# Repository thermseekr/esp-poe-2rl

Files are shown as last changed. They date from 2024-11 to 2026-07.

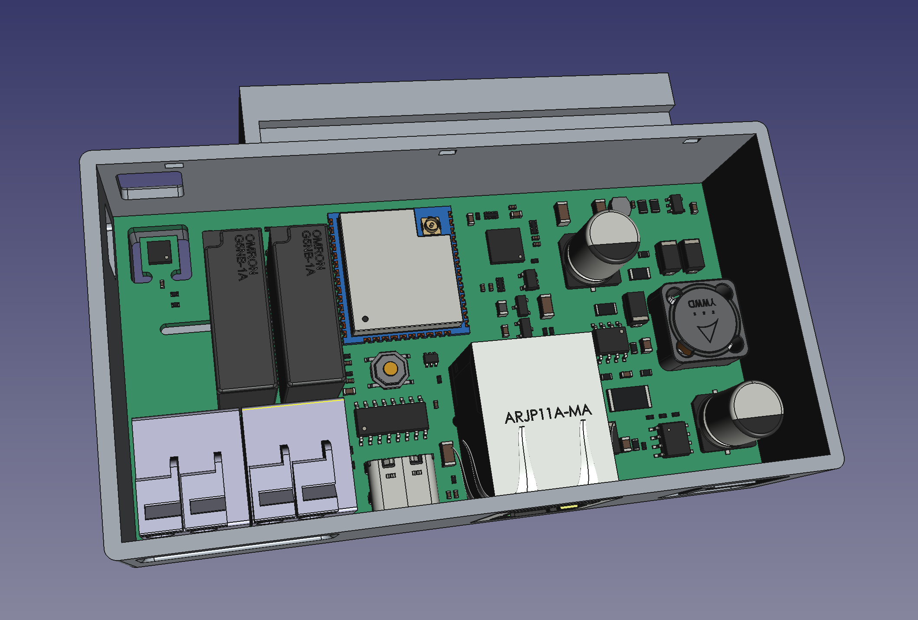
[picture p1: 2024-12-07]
V1/case-inside.png

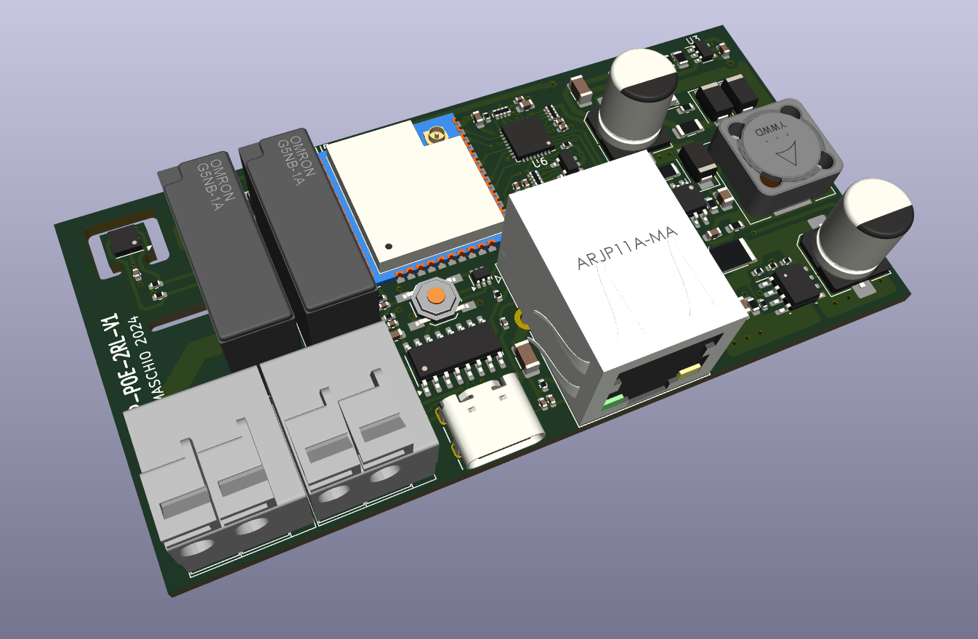
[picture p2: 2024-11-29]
V1/esp-poe-2rl-V1.1.0.png

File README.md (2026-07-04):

# eumesmo-poe-2rl
PoE powered ESP32 based board featuring two SPST NO relays. Ideal for access control, doors, isolated zones or for installing anywhere you need to click dry contacts near some equipment or appliance.

eumesmo-poe-2rl

## VERSION HISTORY

V1.6 - 2026/07/02 - Added CPU health LED.

V1.5 - 2026/06/13 - Repository renamed from ESP-POE-2RL to eumesmo-poe-2rl to align the design with the **eumesmo** line of building automation products.

V1.4 - 2026/06/10 - Terminal blocks replaced for 3.5mm pitch. Deleted temperature sensor, board decreased 8mm in length. LAN8710A rotated for shorter traces. Pull-up resistor for MDIO adjusted from 2.2k to 1.5k as suggested in the datasheet. Bulk and decoupling capacitor sizes and types adjusted for better performance.

V1.3 - 2025/06/29 - Layers reordered and board fully rerouted for better signal integrity.

V1.2 - 2024/12/07 - Connectors adjusted for best fitting the case.

V1.1 - 2024/11/29 - Initial release.

## LICENSE

This project is licensed under the [Creative Commons BY-NC 4.0 License](https://creativecommons.org/licenses/by-nc/4.0/).
Commercial use is not permitted without prior written consent. See the [LICENSE.txt](LICENSE.txt) file for details.

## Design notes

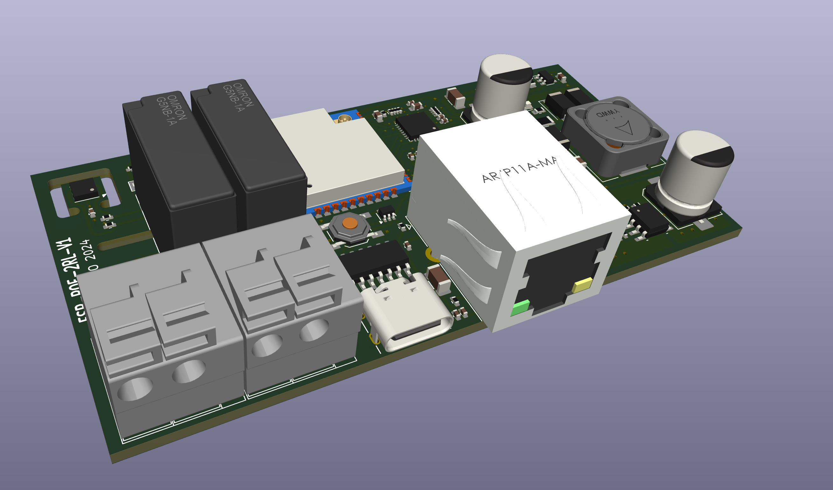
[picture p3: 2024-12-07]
V1/esp-poe-2rl-V1.2.0.png

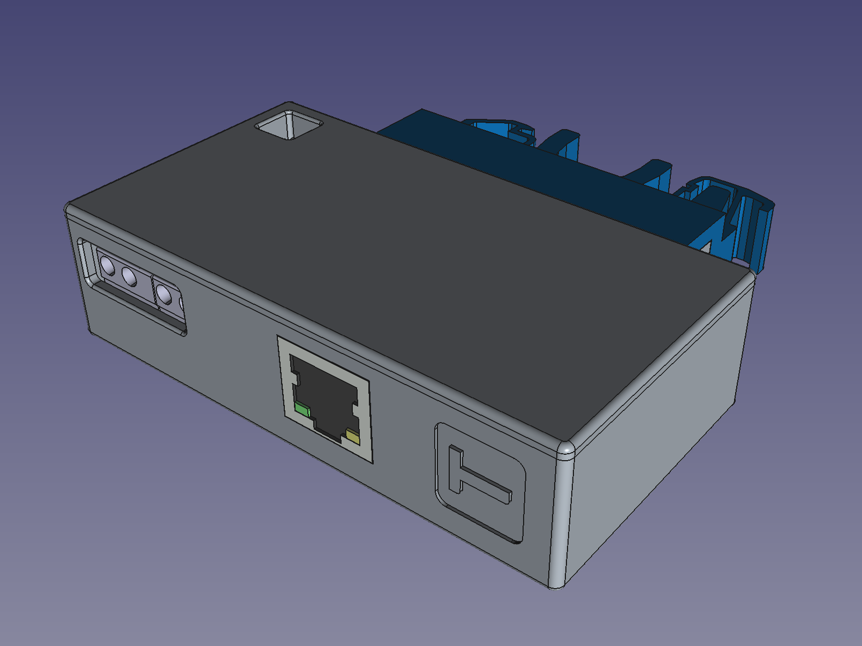
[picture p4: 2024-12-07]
V1/case-front.png

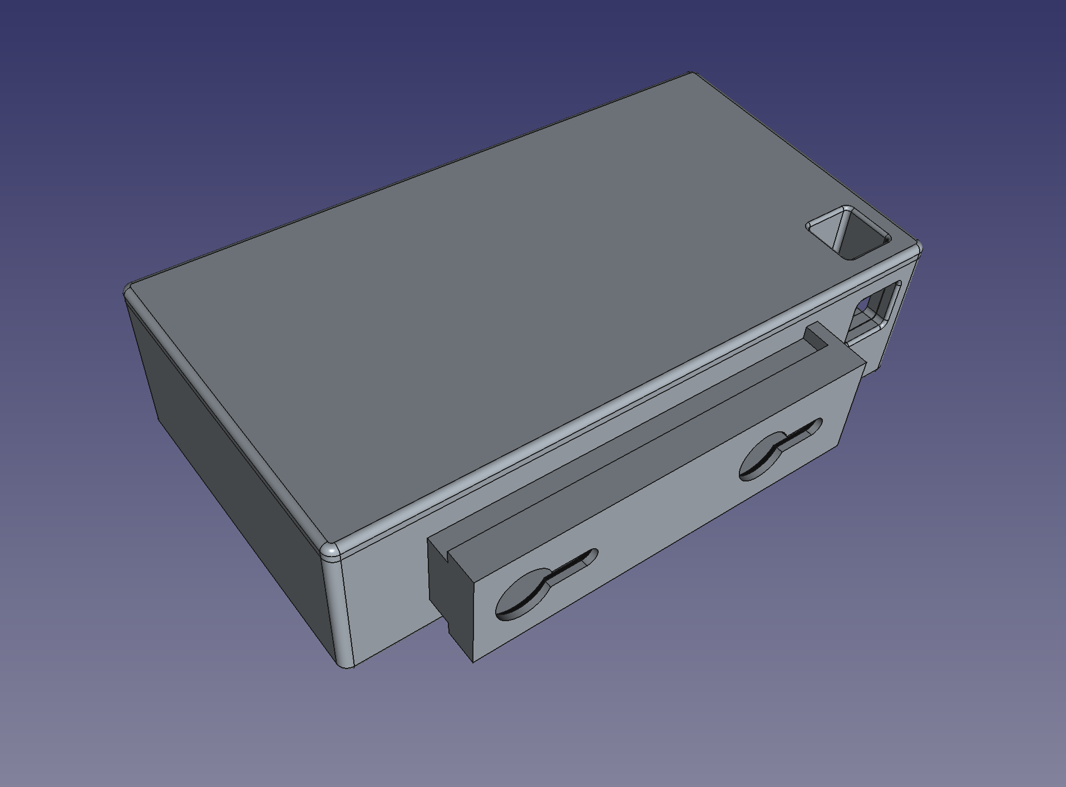
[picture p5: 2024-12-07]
V1/case-back-no-din.png

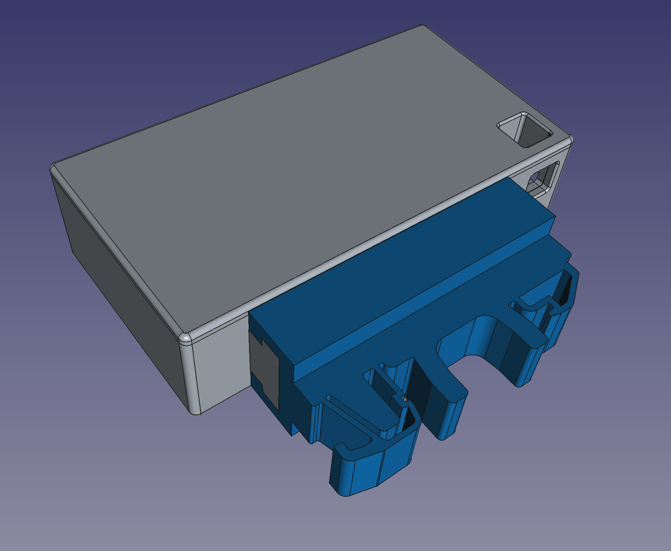
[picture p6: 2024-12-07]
V1/case-back.png

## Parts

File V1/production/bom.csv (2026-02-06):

Designator | Footprint | Quantity | Value | LCSC Part #
C1, C22, C25 | 1206 | 3 | 22uF/10V | C5672
C10, C11, C12, C13, C4, C6 | 0402 | 6 | 100nF/50V | C307331
C14, C18, C3, C5, C8 | 0603 | 5 | 10uF/10V | C19702
C15, C2, C7 | 0402 | 3 | 1uF/25V | C52923
C16 | 0402 | 1 | 470pF/50V | C1537
C17, C19 | 0805 | 2 | 100nF/100V | C28233
C20 | 0402 | 1 | 22pF/50V | C1555
C21 | 0603 | 1 | 12pF/50V | C38523
C23 | CP_Elec_8x10.5 | 1 | 22uF/100V | C178570
C24 | CP_Elec_8x10.5 | 1 | 470uF/16V | C96179
C9 | 1206 | 1 | 1nF/2kV | C161353
D1 | SOT-23-6 | 1 | USBLC6-2SC6 | C7519
D10, D2, D3 | 0603 | 3 | WHITE | C2290
D11 | D_SMA | 1 | SS510 | C65010
D4, D5 | D_SOD-123 | 2 | 1N4148 | C81598
D6 | SOT-23-5 | 1 | ESDS314DBV | C1847859
D7 | D_SMA | 1 | SMAJ58A | C132936
D8, D9 | D_SMA | 2 | SS34 | C8678
J1 | USB_C_Receptacle_GCT_USB4105-xx-A_16P_TopMnt_Horizontal | 1 | USB_C_Receptacle_USB2.0 | C2765186
J2, J3 | TerminalBlock_Dibo_DB142R-5.08-2P_1x02_P5.08mm_Horizontal | 2 | 1x2P 5,08mm | C475144
J4 | RJ45_HanRun_HY931147C | 1 | RJ45 JACK | C91754
K1, K2 | Relay_SPST_Omron_G5NB-1A | 2 | G5NB-1A-E-DC5 | C48746
L1 | 0805 | 1 | 2A/600R | C139168
L2 | L_12x12mm_h6mm | 1 | 33uH/2,1A | C169386
L3 | L_3x3mm_h1.5mm | 1 | 2,2uH/1,5A | C370424
Q1 | SOT-23 | 1 | WPM2015-3/TR | C558305
Q2 | SOT-23 | 1 | LMUN2211LT1G | C150229
Q3 | SOT-363_SC-70-6 | 1 | UMH3N | C62892
Q4, Q5 | SOT-23 | 2 | MMBT2222A | C8512
R1, R11, R12, R14, R15, R28, R5, R6 | 0402 | 8 | 10k | C60490
R10, R9 | 0402 | 2 | 680R | C25130
R13 | 0402 | 1 | 22R | C25092
R16 | 0402 | 1 | 12,1k | C25852
R17, R18 | 0402 | 2 | 330R | C25104
R19 | 1206 | 1 | 30mR/250mW | C473665
R2, R4 | 0402 | 2 | 5,1k | C105872
R20, R3, R7, R8 | 0402 | 4 | 1k | C11702
R21 | 0402 | 1 | 180k | C138046
R22 | 0402 | 1 | 30,1k | C138009
R23 | 0603 | 1 | 4,42k/100mW | C482858
R24 | 0603 | 1 | 5,1R/100mW | C25197
R25 | 0805 | 1 | 100k/0,125W | C149504
R26 | 0805 | 1 | 22,1k/0,125W | C17552
R27 | 0402 | 1 | 130k | C93946
R29 | 0603 | 1 | 300k/100mW | C23024
R30 | 0603 | 1 | 52,3k/100mW | C185323
R31 | 2512 | 1 | 4,7k/1W | C878291
R32, R33, R34, R35 | 0402 | 4 | 49,9R | C25120
R36, R37, R38, R39, R40, R41, R42, R43 | 0402 | 8 | 2k2 | C25879
SW1 | SW_SPST_Xunpu_TS1088AR02016 | 1 | RESET | C720477
U1 | SSOP-10-1EP_3.9x4.9mm_P1mm_EP2.1x3.3mm | 1 | CH340K | C968586
U2 | ESP32-WROOM-32U | 1 | ESP32-WROOM-32UE-N16 | C701346
U3 | QFN-32-1EP_5x5mm_P0.5mm_EP3.3x3.3mm_ThermalVias | 1 | LAN8710A | C46185
U4 | SOIC-8-1EP_3.9x4.9mm_P1.27mm_EP2.41x3.81mm_ThermalVias | 1 | TX4138 | C329267
U5 | SOT-23-5_Shorter_Pins | 1 | SY8089A1AAC | C479074
U6 | SOIC-8-1EP_3.9x4.9mm_P1.27mm_EP2.95x4.9mm_Mask2.71x3.4mm_ThermalVias | 1 | TPS2376DDAR-H | C544899

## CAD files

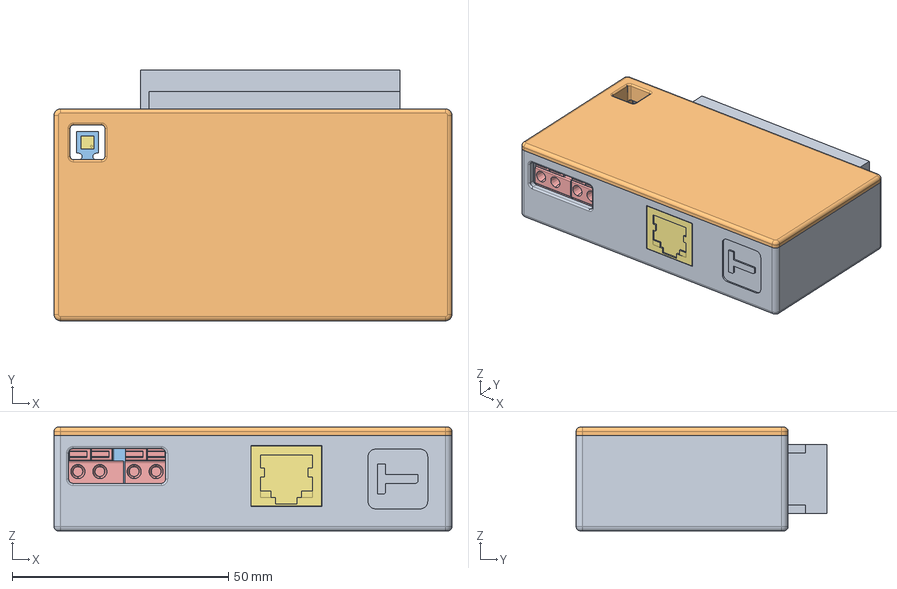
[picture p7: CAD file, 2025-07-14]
V1/esp-poe-2rl-V1.FCStd
92.0 x 58.0 x 24.0 mm
base
tampa
Pcb_c889
Q2_SOT_23_4970d7121a076 x 4
J3_DB142R-508-1P_a4dc8ad2a203 x 2
R23_R_0402_1005Metric_0b1d7b5ca681 x 24
C10_C_0402_1005Metric_ed852e6b843f001 x 12
SW1_3x4x2mm - 2 button_e5fc0649a69a
C6_C_0603_1608Metric_744dddbd0627 x 6
R8_R_0603_1608Metric_64182718e303 x 5
U6_QFN_32_1EP_5x5mm_P05mm_EP33x33mm_efa93686acdd001
D3_D_SMA_e0da9ef18898 x 4
C3_C_0805_2012Metric_58c3552bee014 x 2
U4_SOIC_16_39x99mm_P127mm_c005a263dd071
J2_ARJP11A_ARJP11A-MA_68af04fa2421
C8_C_1206_3216Metric_09ed0d5bb760 x 4
U5_ESP32-WROOM-32U_007640470fe010
U3_TSOT_23_5_e862bd6dc8b008
USB_C_Receptacle_16P_TopMnt_Horizontal_GCT_USB4105-xx-A036
USB_C_Receptacle_16P_TopMnt_Horizontal_GCT_USB4105-xx-A037
USB_C_Receptacle_16P_TopMnt_Horizontal_GCT_USB4105-xx-A038
USB_C_Receptacle_16P_TopMnt_Horizontal_GCT_USB4105-xx-A039
USB_C_Receptacle_16P_TopMnt_Horizontal_GCT_USB4105-xx-A040
USB_C_Receptacle_16P_TopMnt_Horizontal_GCT_USB4105-xx-A041
USB_C_Receptacle_16P_TopMnt_Horizontal_GCT_USB4105-xx-A042
USB_C_Receptacle_16P_TopMnt_Horizontal_GCT_USB4105-xx-A043
USB_C_Receptacle_16P_TopMnt_Horizontal_GCT_USB4105-xx-A044
USB_C_Receptacle_16P_TopMnt_Horizontal_GCT_USB4105-xx-A045
USB_C_Receptacle_16P_TopMnt_Horizontal_GCT_USB4105-xx-A046
USB_C_Receptacle_16P_TopMnt_Horizontal_GCT_USB4105-xx-A047
USB_C_Receptacle_16P_TopMnt_Horizontal_GCT_USB4105-xx-A048
USB_C_Receptacle_16P_TopMnt_Horizontal_GCT_USB4105-xx-A049
USB_C_Receptacle_16P_TopMnt_Horizontal_GCT_USB4105-xx-A050
USB_C_Receptacle_16P_TopMnt_Horizontal_GCT_USB4105-xx-A051
USB_C_Receptacle_16P_TopMnt_Horizontal_GCT_USB4105-xx-A052
USB_C_Receptacle_16P_TopMnt_Horizontal_GCT_USB4105-xx-A053
USB_C_Receptacle_16P_TopMnt_Horizontal_GCT_USB4105-xx-A054
USB_C_Receptacle_16P_TopMnt_Horizontal_GCT_USB4105-xx-A055
USB_C_Receptacle_16P_TopMnt_Horizontal_GCT_USB4105-xx-A056
USB_C_Receptacle_16P_TopMnt_Horizontal_GCT_USB4105-xx-A057
USB_C_Receptacle_16P_TopMnt_Horizontal_GCT_USB4105-xx-A058
USB_C_Receptacle_16P_TopMnt_Horizontal_GCT_USB4105-xx-A059
USB_C_Receptacle_16P_TopMnt_Horizontal_GCT_USB4105-xx-A060
USB_C_Receptacle_16P_TopMnt_Horizontal_GCT_USB4105-xx-A061
USB_C_Receptacle_16P_TopMnt_Horizontal_GCT_USB4105-xx-A062
USB_C_Receptacle_16P_TopMnt_Horizontal_GCT_USB4105-xx-A063
USB_C_Receptacle_16P_TopMnt_Horizontal_GCT_USB4105-xx-A064
USB_C_Receptacle_16P_TopMnt_Horizontal_GCT_USB4105-xx-A065
USB_C_Receptacle_16P_TopMnt_Horizontal_GCT_USB4105-xx-A066
USB_C_Receptacle_16P_TopMnt_Horizontal_GCT_USB4105-xx-A067
USB_C_Receptacle_16P_TopMnt_Horizontal_GCT_USB4105-xx-A068
USB_C_Receptacle_16P_TopMnt_Horizontal_GCT_USB4105-xx-A069
USB_C_Receptacle_16P_TopMnt_Horizontal_GCT_USB4105-xx-A070
USB_C_Receptacle_16P_TopMnt_Horizontal_GCT_USB4105-xx-A071
F1_Fuse_1206_3216Metric_39f227ff16b009
D5_LED_0603_1608Metric_6aec2e6d64af001 x 3
Q1_SOT_363_SC_70_6_453209e6e602
L3_L_0805_2012Metric_3eca19b2d063
C2_CP_Elec_8x105_1f412a5b28ca001 x 2
U7_DFN_6_1EP_3x3mm_Pitch1mm_b88c4946fe064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

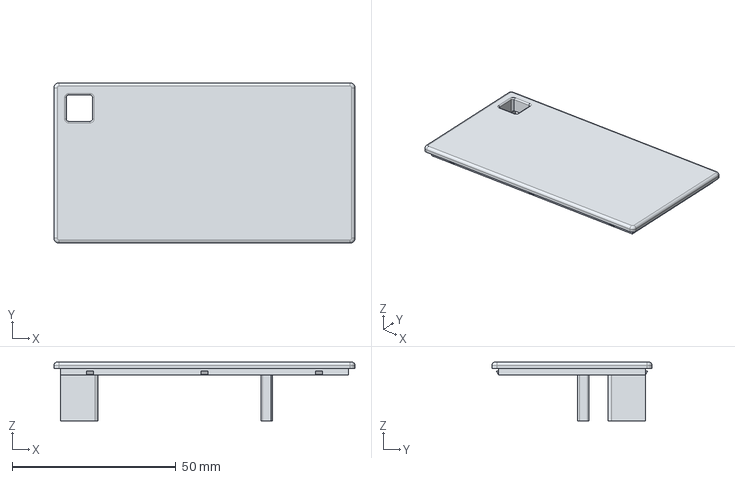
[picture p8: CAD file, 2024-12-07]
V1/esp-poe-2rl-V1-CaixaTampa.step
92.0 x 49.0 x 18.0 mm

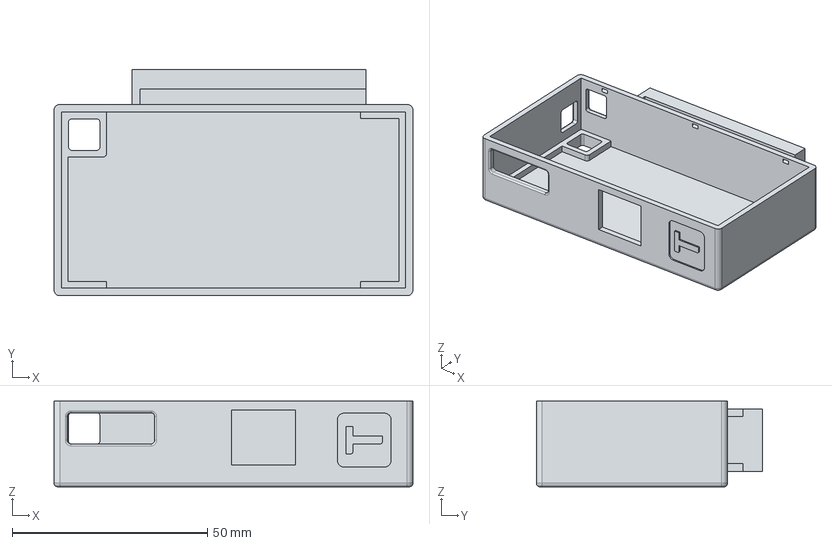
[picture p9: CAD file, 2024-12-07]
V1/esp-poe-2rl-V1-CaixaBase.step
92.0 x 58.0 x 22.0 mm

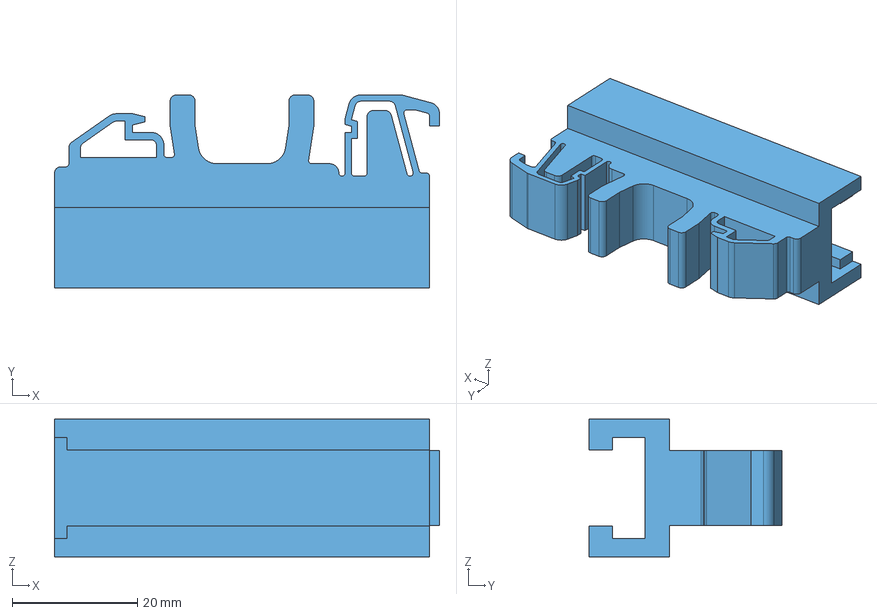
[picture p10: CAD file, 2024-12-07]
V1/esp-poe-2rl-V1-Encaixe-DIN.step
61.6 x 30.9 x 22.0 mm

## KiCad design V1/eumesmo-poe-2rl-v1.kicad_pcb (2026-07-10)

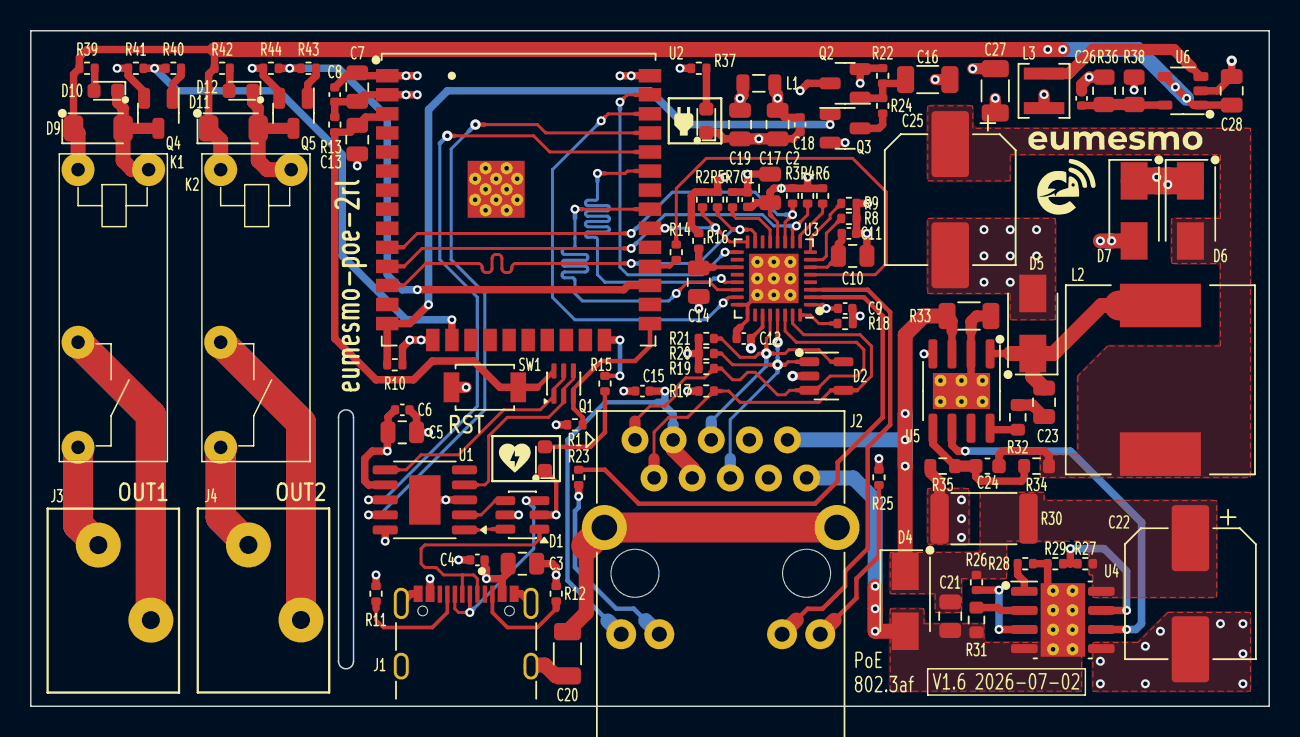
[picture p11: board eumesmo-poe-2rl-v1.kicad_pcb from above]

Board: 4 copper layers, 82.5 x 45.0 mm, 105 parts (0 on the bottom side), 77 nets.

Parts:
C1, C4, C6, C8, C9, C12, C15, C18: 100nF/50V; C_0402_1005Metric
C2, C5, C7, C14, C17, C19, C28: 10uF/25V; C_0805_2012Metric
C3, C10, C13: 1uF/50V; C_0805_2012Metric
C11: 470pF/50V; C_0402_1005Metric
C16, C27: 22uF/10V; C_1206_3216Metric
C20: 1nF/2kV; C_1206_3216Metric
C21, C23: 100nF/100V; C_0805_2012Metric
C22: 22uF/100V; CP_Elec_8x10.5
C24: 12pF/50V; C_0603_1608Metric
C25: 470uF/16V; CP_Elec_8x10.5
C26: 22pF/50V; C_0402_1005Metric
D1: USBLC6-2SC6; SOT-23-6
D2: ESDS314DBV; SOT-23-5
D3: WHITE/0603; LED_0603_1608Metric
D4: SMAJ58A; D_SMA
D5: SS510; D_SMA
D6, D7: SS34; D_SMA
D8, D10, D12: WHITE; LED_0603_1608Metric
D9, D11: 1N4148; D_SOD-123
J1: USB_C_Receptacle_USB2.0; USB_C_Receptacle_GCT_USB4105-xx-A_16P_TopMnt_Horizontal
J2: RJ45 JACK; RJ45_HanRun_HY931147C
J3, J4: 250-202; TerminalBlock_Wago_250-202_1x02_P3.5mm_45Degree
K1, K2: G5NB-1A-E-DC5; Relay_SPST_Omron_G5NB-1A
L1: 2A/600R; L_0805_2012Metric
L2: 33uH/2,1A; L_12x12mm_H6mm
L3: 2,2uH/1,5A; L_3x3mm_H1.5mm
Q1: UMH3N; SOT-363_SC-70-6
Q2: WPM2015-3/TR; SOT-23
Q3: LMUN2211LT1G; SOT-23
Q4, Q5: MMBT2222A; SOT-23
R1, R10, R13, R16, R22, R29, R41, R44: 10k; R_0402_1005Metric
R2: 1.5k; R_0402_1005Metric
R3, R4, R5, R6, R7, R8, R9: 2.2k; R_0402_1005Metric
R11, R12: 5,1k; R_0402_1005Metric
R14: 33R; R_0402_1005Metric
R15, R37: 300R; R_0402_1005Metric
R17, R19, R20, R21: 49,9R; R_0402_1005Metric
R18: 12,1k; R_0402_1005Metric
R23, R25: 330R; R_0402_1005Metric
R24, R40, R43: 1k; R_0402_1005Metric
R26: 30,1k; R_0402_1005Metric
R27: 130k; R_0402_1005Metric
R28: 180k; R_0402_1005Metric
R30: 4,7k/1W; R_2512_6332Metric
R31: 4,42k/100mW; R_0603_1608Metric
R32: 5,1R/100mW; R_0603_1608Metric
R33: 30mR/250mW; R_1206_3216Metric
R34: 300k/100mW; R_0603_1608Metric
R35: 52,3k/100mW; R_0603_1608Metric
R36: 100k/0,125W; R_0805_2012Metric
R38: 22,1k/0,125W; R_0805_2012Metric
R39, R42: 680R; R_0402_1005Metric
SW1: RESET; SW_SPST_Xunpu_TS1088AR02016
U1: CH340K; SSOP-10-1EP_3.9x4.9mm_P1mm_EP2.1x3.3mm
U2: ESP32-WROOM-32UE-N16; ESP32-WROOM-32U
U3: LAN8710A; QFN-32-1EP_5x5mm_P0.5mm_EP3.3x3.3mm_ThermalVias
U4: TPS2376DDAR-H; SOIC-8-1EP_3.9x4.9mm_P1.27mm_EP2.95x4.9mm_Mask2.71x3.4mm_Th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
U5: TX4138; SOIC-8-1EP_3.9x4.9mm_P1.27mm_EP2.41x3.81mm_ThermalVias
U6: SY8089A1AAC; SOT-23-5_Shorter_Pins

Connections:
5VPOE: C24.1, C25.1, D6.2 (A), L2.2, R34.1
5VUSB: C3.1, C4.1, D1.5 (VBUS), D7.2 (A), J1.A4 (VBUS), J1.A9 (VBUS), J1.B4 (VBUS), J1.B9 (VBUS)
+3V3: C5.1, C6.1, C7.1, C8.1, C16.1, C26.1, C27.1, L3.2, Q2.2 (S), R1.1, R13.1, R22.1, R36.1, R37.1, U1.7 (VCC), U1.10 (V3), U2.2 (VDD)
+3V3A: C9.1, C12.1, C15.1, C19.1, J2.3 (CT), J2.4 (CT), J2.11 (LLED+), L1.2, R17.2, R19.2, R20.2, R21.2, U3.1 (VDD2A), U3.27 (VDD1A)
+3V3LAN: C1.1, C2.1, C17.1, C18.1, L1.1, Q2.3 (D), R2.1, R3.1, R4.1, R5.1, R6.1, R16.2, U3.12 (VDDIO)
+5V: C28.1, D6.1 (K), D7.1 (K), D9.1 (K), D11.1 (K), K1.1, K2.1, R39.1, R42.1, U6.1 (EN), U6.4 (IN)
/CPULED: D3.2 (A), R15.2
/CPUOK: R15.1, U2.24 (IO2)
/EMACCLK: R14.2, U3.5 (XTAL1/CLKIN)
/EMACMDC: U2.37 (IO23), U3.17 (MDC)
/EMACMDIO: R2.2, U2.30 (IO18), U3.16 (MDIO)
/EMACRX: R5.2, U2.12 (IO27), U3.15 (COL/CRS_DV/~MODE2)
/EMACRXCLK: R8.2, U3.7 (RXCLK/~PHYAD1)
/EMACRXD0: R3.2, U2.10 (IO25), U3.11 (RXD0/~MODE0)
/EMACRXD1: R4.2, U2.11 (IO26), U3.10 (RXD1/~MODE1)
/EMACRXD2: R6.2, U3.9 (RXD2/~RMIISEL)
/EMACRXD3: R9.2, U3.8 (RXD3/~PHYAD2)
/EMACRXD4: R7.2, U3.13 (RXER/RXD4/~PHYAD0)
/EMACTXD0: U2.31 (IO19), U3.22 (TXD0)
/EMACTXD1: U2.36 (IO22), U3.23 (TXD1)
/EMACTXEN: U2.33 (IO21), U3.21 (TXEN)
/ESPCLK: R14.1, U2.28 (IO17)
/ESPEN: C13.1, Q1.6 (C1), R13.2, SW1.2, U2.3 (EN)
/ESPPROG: Q1.3 (C2), R1.2, U2.25 (IO0)
/ETHLEDGA: J2.13 (RLED+), U3.3 (LED1/~REGOFF)
/ETHLEDGK: J2.14 (RLED-), R25.2
/ETHLEDY: R23.2, U3.2 (LED2/~INTSEL)
/ETHLEDYK: J2.12 (LLED-), R23.1
/ETHRXD+: D2.4 (I/03), J2.2 (RD+), R17.1, U3.31 (RXP)
/ETHRXD-: D2.3 (I/02), J2.1 (RD-), R19.1, U3.30 (RXN)
/ETHSH: C20.1, J2.15 (SHIELD)
/ETHTXD+: D2.1 (I/01), J2.6 (TD+), R20.1, U3.29 (TXP)
/ETHTXD-: D2.5 (I/04), J2.5 (TD-), R21.1, U3.28 (TXN)
/PHYNRST: C14.2, R16.1, U3.19 (~RST)
/PHYPWRBJT: Q3.3 (C), R24.2
/PHYPWRFET: C16.2, Q2.1 (G), R22.2, R24.1
/POWER/3V3LED: D8.2 (A), R37.2
/POWER/3V3REF: C26.2, R36.2, R38.1, U6.5 (FB)
/POWER/3V3SW: L3.1, U6.3 (LX)
/POWER/5VBS: C23.1, R32.1
/POWER/5VREF: C24.2, R34.2, R35.1, U5.5 (FB)
/POWER/5VSW: C23.2, D5.1 (K), L2.1, U5.1 (SW)
/POWER/BS: R32.2, U5.8 (BS)
/POWER/ILIM: R33.2, U5.2 (ILIM), U5.9 (ILIM)
/POWER/RCLASS: R31.1, U4.2 (CLASS)
/POWER/RDET: R26.2, U4.3 (DET)
/POWER/RILIM: R28.1, U4.1 (ILIM)
/POWER/VTAP: R27.2, R29.1, U4.7 (UVLO)
/RBIAS: R18.1, U3.32 (RBIAS)
/RELAY OUTPUTS/OUT1BJT: Q4.1 (B), R40.1
/RELAY OUTPUTS/OUT1CMD: D9.2 (A), D10.1 (K), K1.4, Q4.3 (C)
/RELAY OUTPUTS/OUT1LD: J3.1, K1.3
/RELAY OUTPUTS/OUT1LN: J3.2, K1.2
/RELAY OUTPUTS/OUT1ON: D10.2 (A), R39.2
/RELAY OUTPUTS/OUT2BJT: Q5.1 (B), R43.1
/RELAY OUTPUTS/OUT2CMD: D11.2 (A), D12.1 (K), K2.4, Q5.3 (C)
/RELAY OUTPUTS/OUT2LD: J4.1, K2.3
/RELAY OUTPUTS/OUT2LN: J4.2, K2.2
/RELAY OUTPUTS/OUT2ON: D12.2 (A), R42.2
/UARTNDTR: Q1.2 (B1), Q1.4 (E2), U1.4 (~DTR)
/UARTNRTS: Q1.1 (E1), Q1.5 (B2), U1.6 (~RTS)
/UARTRXD: U1.9 (RXD), U2.35 (TXD0/IO1)
/UARTTXD: U1.8 (TXD), U2.34 (RXD0/IO3)
/USBCC1: J1.A5 (CC1), R11.1
/USBCC2: J1.B5 (CC2), R12.1
/USBCD+: D1.1 (I/O1), J1.A6 (D+), J1.B6 (D+)
/USBCD-: D1.3 (I/O2), J1.A7 (D-), J1.B7 (D-)
/USBD+: D1.6 (I/O1), U1.1 (UD+)
/USBD-: D1.4 (I/O2), U1.2 (UD-)
/VDDCR: C10.1, C11.1, U3.6 (VDDCR)
GND: C1.2, C2.2, C3.2, C4.2, C5.2, C6.2, C7.2, C8.2, C9.2, C10.2, C11.2, C12.2, C13.2, C14.1, C15.2, C17.2, C18.2, C19.2, C20.2, C22.2, C25.2, C27.2, C28.2, D1.2 (GND), D2.2 (GND), D3.1 (K), D5.2 (A), D8.1 (K), J1.A1 (GND), J1.A12 (GND), J1.B1 (GND), J1.B12 (GND), J1.S1 (SHIELD), Q3.2 (E), Q4.2 (E), Q5.2 (E), R7.1, R8.1, R9.1, R10.1, R11.2, R12.2, R18.2, R25.1, R30.2, R35.2, R38.2, R41.2, R44.2, SW1.1, U1.3 (GND), U1.11 (GND), U2.1 (GND), U2.15 (GND), U2.38 (GND), U2.39 (GND), U3.24 (TXD2), U3.25 (TXD3), U3.33 (VSS), U4.5 (RTN), U5.4 (GND), U6.2 (GND)
OUT1: R40.2, R41.1, U2.16 (IO13)
OUT2: R43.2, R44.1, U2.27 (IO16)
PG: U4.6 (PG), U5.6 (EN)
PHYPWR: Q3.1 (B), R10.2, U2.14 (IO12)
POE+: C21.1, C22.1, D4.1 (K), J2.9 (V+), R26.1, R27.1, R30.1, R33.1, U4.8 (VDD), U5.3 (VIN)
POE-: C21.2, D4.2 (A), J2.10 (V-), R28.2, R29.2, R31.2, U4.4 (VSS), U4.9 (PPAD)

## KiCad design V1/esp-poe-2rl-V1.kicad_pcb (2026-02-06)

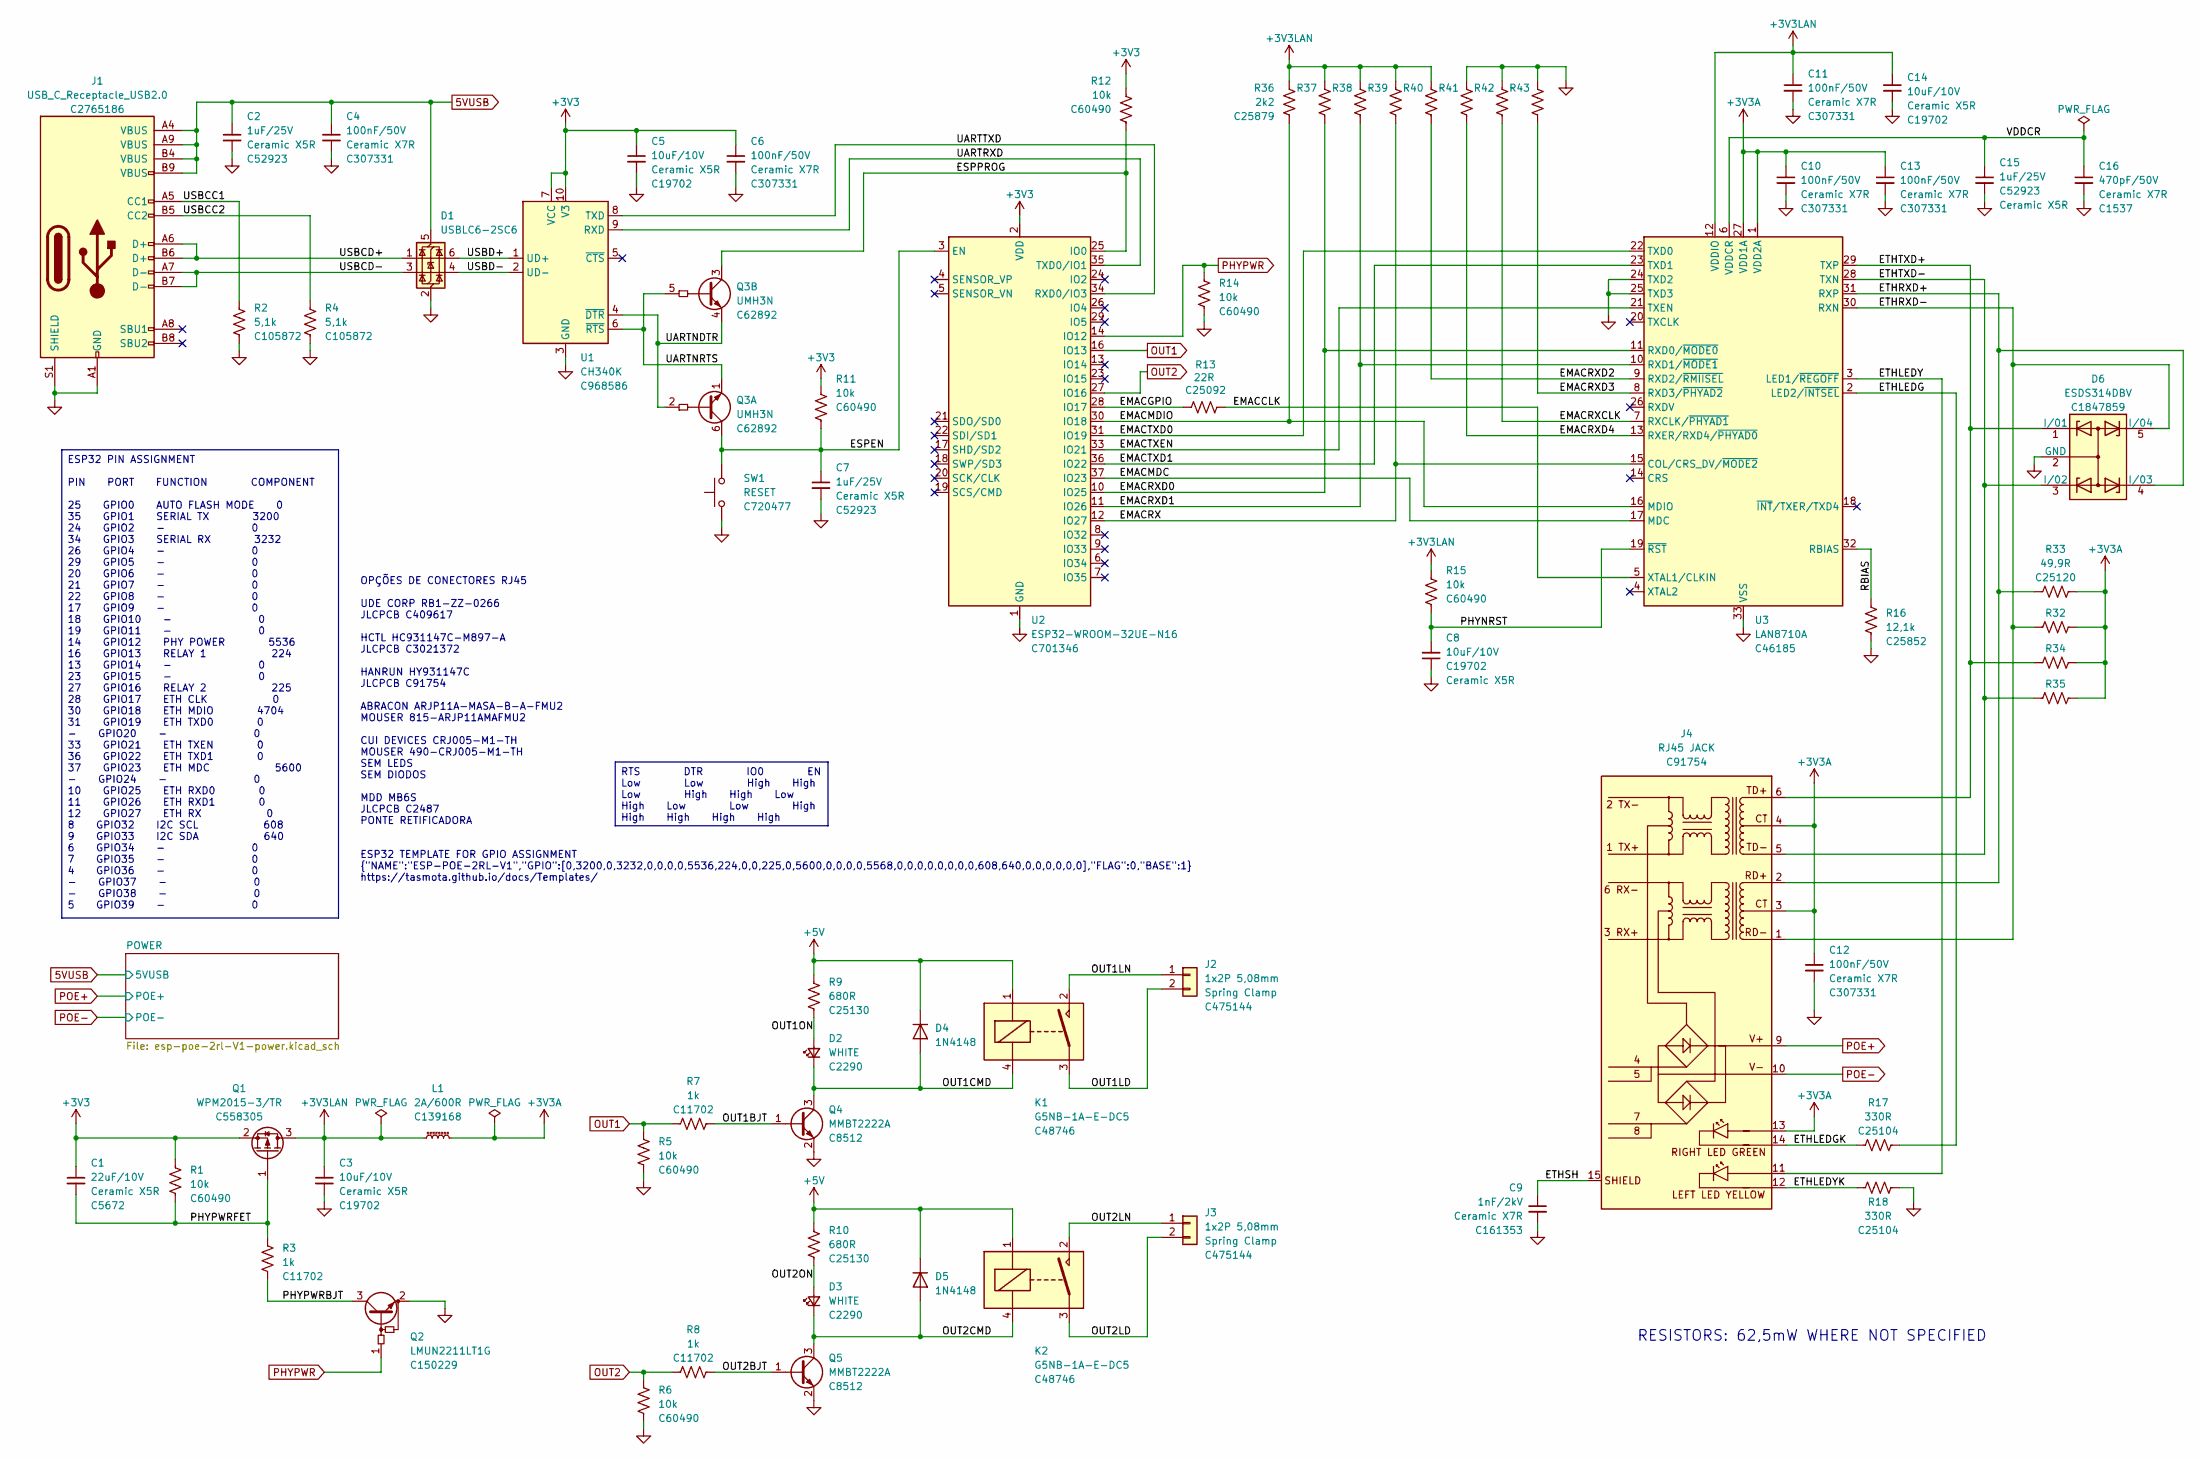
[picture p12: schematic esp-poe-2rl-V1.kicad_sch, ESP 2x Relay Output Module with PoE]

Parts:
C1: 22uF/10V; C_1206_3216Metric; Mfr PN CL31A226KPHNNNE; JLCPCB BOM 1
C2, C7, C15: 1uF/25V; C_0402_1005Metric; Mfr PN CL05A105KA5NQNC; JLCPCB BOM 1
C3, C8, C14: 10uF/10V; C_0603_1608Metric; Mfr PN CL10A106KP8NNNC; JLCPCB BOM 1
C4, C6, C10, C11, C12, C13: 100nF/50V; C_0402_1005Metric; Mfr PN CL05B104KB54PNC; JLCPCB BOM 1
C5: 10uF/10V; C_0603_1608Metric; Mfr PN CL10A106KP8NNNC; LCSC Part # C19702
C9: 1nF/2kV; C_1206_3216Metric; Mfr PN GR431BR7LA102KW66L; JLCPCB BOM 1
C16: 470pF/50V; C_0402_1005Metric; Mfr PN 0402B471K500NT; JLCPCB BOM 1
D1: USBLC6-2SC6; SOT-23-6; Mfr PN USBLC6-2SC6; JLCPCB BOM 1
D2, D3: WHITE; LED_0603_1608Metric; Mfr PN KT-0603W; LCSC Part # C2290
D4, D5: 1N4148; D_SOD-123; Mfr PN 1N4148W; JLCPCB BOM 1
D6: ESDS314DBV; SOT-23-5; Mfr PN ESDS314DBVR; JLCPCB BOM 1
J1: USB_C_Receptacle_USB2.0; USB_C_Receptacle_GCT_USB4105-xx-A_16P_TopMnt_Horizontal; Mfr PN TYPE-C 16PIN 2MD(073); JLCPCB BOM 1
J2, J3: 1x2P 5,08mm; TerminalBlock_Dibo_DB142R-5.08-2P_1x02_P5.08mm_Horizontal; Mfr PN KF142R-5.08-2P; JLCPCB BOM 1
J4: RJ45 JACK; RJ45_HanRun_HY931147C; Mfr PN HY931147C; JLCPCB BOM 1
K1, K2: G5NB-1A-E-DC5; Relay_SPST_Omron_G5NB-1A; Mfr PN G5NB-1A-E-DC5; JLCPCB BOM 1
L1: 2A/600R; L_0805_2012Metric; Mfr PN CBM201209U601T; JLCPCB BOM 1
Q1: WPM2015-3/TR; SOT-23; Mfr PN WPM2015-3/TR; JLCPCB BOM 1
Q2: LMUN2211LT1G; SOT-23; Mfr PN MMUN2211LT3G; LCSC Part # C150229
Q3: UMH3N; SOT-363_SC-70-6; Mfr PN UMH3N; JLCPCB BOM 1
Q4, Q5: MMBT2222A; SOT-23; Mfr PN MMBT2222A; JLCPCB BOM 1
R1, R5, R6, R11, R12, R14, R15: 10k; R_0402_1005Metric; Mfr PN RC0402FR-0710KL; LCSC Part # C60490
R2, R4: 5,1k; R_0402_1005Metric; Mfr PN RC0402FR-075K1L; JLCPCB BOM 1
R3, R7, R8: 1k; R_0402_1005Metric; Mfr PN 0402WGF1001TCE; LCSC Part # C11702
R9, R10: 680R; R_0402_1005Metric; Mfr PN 0402WGF6800TCE; LCSC Part # C25130
R13: 22R; R_0402_1005Metric; Mfr PN 0402WGF220JTCE; JLCPCB BOM 1
R16: 12,1k; R_0402_1005Metric; Mfr PN 0402WGF1212TCE; JLCPCB BOM 1
R17, R18: 330R; R_0402_1005Metric; Mfr PN 0402WGF3300TCE; LCSC Part # C25104
R32, R33, R34, R35: 49,9R; R_0402_1005Metric; Mfr PN 0402WGF499JTCE; JLCPCB BOM 1
R36, R37, R38, R39, R40, R41, R42, R43: 2k2; R_0402_1005Metric; Mfr PN 0402WGF2201TCE; LCSC Part # C25879
SW1: RESET; SW_SPST_Xunpu_TS1088AR02016; Mfr PN TS-1088-AR02016; JLCPCB BOM 1
U1: CH340K; SSOP-10-1EP_3.9x4.9mm_P1mm_EP2.1x3.3mm; Mfr PN CH340K; JLCPCB BOM 1
U2: ESP32-WROOM-32UE-N16; ESP32-WROOM-32U; Mfr PN ESP32-WROOM-32UE-N16; JLCPCB BOM 1
U3: LAN8710A; QFN-32-1EP_5x5mm_P0.5mm_EP3.3x3.3mm_ThermalVias; Mfr PN LAN8710A-EZC-TR; JLCPCB BOM 1

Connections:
5VUSB: C2.1, C4.1, D1.5 (VBUS), J1.A4 (VBUS), J1.A9 (VBUS), J1.B4 (VBUS), J1.B9 (VBUS); also elsewhere on the board
+3V3: C1.1, C5.1, C6.1, Q1.2 (S), R1.1, R11.1, R12.1, U1.7 (VCC), U1.10 (V3), U2.2 (VDD); also elsewhere on the board
+3V3A: C10.1, C12.1, C13.1, J4.3 (CT), J4.4 (CT), J4.13 (RLED+), L1.2, R32.2, R33.2, R34.2, R35.2, U3.1 (VDD2A), U3.27 (VDD1A)
+3V3LAN: C3.1, C11.1, C14.1, L1.1, Q1.3 (D), R15.2, R36.1, R37.1, R38.1, R39.1, R40.1, U3.12 (VDDIO)
+5V: D4.1 (K), D5.1 (K), K1.1, K2.1, R9.1, R10.1; also elsewhere on the board
/EMACCLK: R13.2, U3.5 (XTAL1/CLKIN)
/EMACGPIO: R13.1, U2.28 (IO17)
/EMACMDC: U2.37 (IO23), U3.17 (MDC)
/EMACMDIO: R36.2, U2.30 (IO18), U3.16 (MDIO)
/EMACRX: R39.2, U2.12 (IO27), U3.15 (COL/CRS_DV/~MODE2)
/EMACRXCLK: R42.2, U3.7 (RXCLK/~PHYAD1)
/EMACRXD0: R37.2, U2.10 (IO25), U3.11 (RXD0/~MODE0)
/EMACRXD1: R38.2, U2.11 (IO26), U3.10 (RXD1/~MODE1)
/EMACRXD2: R40.2, U3.9 (RXD2/~RMIISEL)
/EMACRXD3: R43.2, U3.8 (RXD3/~PHYAD2)
/EMACRXD4: R41.2, U3.13 (RXER/RXD4/~PHYAD0)
/EMACTXD0: U2.31 (IO19), U3.22 (TXD0)
/EMACTXD1: U2.36 (IO22), U3.23 (TXD1)
/EMACTXEN: U2.33 (IO21), U3.21 (TXEN)
/ESPEN: C7.1, Q3.6 (C1), R11.2, SW1.2, U2.3 (EN)
/ESPPROG: Q3.3 (C2), R12.2, U2.25 (IO0)
/ETHLEDG: R17.2, U3.2 (LED2/~INTSEL)
/ETHLEDGK: J4.14 (RLED-), R17.1
/ETHLEDY: J4.11 (LLED+), U3.3 (LED1/~REGOFF)
/ETHLEDYK: J4.12 (LLED-), R18.1
/ETHRXD+: D6.4 (I/03), J4.2 (RD+), R33.1, U3.31 (RXP)
/ETHRXD-: D6.5 (I/04), J4.1 (RD-), R32.1, U3.30 (RXN)
/ETHSH: C9.1, J4.15 (SHIELD)
/ETHTXD+: D6.1 (I/01), J4.6 (TD+), R34.1, U3.29 (TXP)
/ETHTXD-: D6.3 (I/02), J4.5 (TD-), R35.1, U3.28 (TXN)
/OUT1BJT: Q4.1 (B), R7.1
/OUT1CMD: D2.1 (K), D4.2 (A), K1.4, Q4.3 (C)
/OUT1LD: J2.2, K1.3
/OUT1LN: J2.1, K1.2
/OUT1ON: D2.2 (A), R9.2
/OUT2BJT: Q5.1 (B), R8.1
/OUT2CMD: D3.1 (K), D5.2 (A), K2.4, Q5.3 (C)
/OUT2LD: J3.2, K2.3
/OUT2LN: J3.1, K2.2
/OUT2ON: D3.2 (A), R10.2
/PHYNRST: C8.2, R15.1, U3.19 (~RST)
/PHYPWRBJT: Q2.3 (C), R3.2
/PHYPWRFET: C1.2, Q1.1 (G), R1.2, R3.1
/RBIAS: R16.1, U3.32 (RBIAS)
/UARTNDTR: Q3.2 (B1), Q3.4 (E2), U1.4 (~DTR)
/UARTNRTS: Q3.1 (E1), Q3.5 (B2), U1.6 (~RTS)
/UARTRXD: U1.9 (RXD), U2.35 (TXD0/IO1)
/UARTTXD: U1.8 (TXD), U2.34 (RXD0/IO3)
/USBCC1: J1.A5 (CC1), R2.1
/USBCC2: J1.B5 (CC2), R4.1
/USBCD+: D1.1 (I/O1), J1.A6 (D+), J1.B6 (D+)
/USBCD-: D1.3 (I/O2), J1.A7 (D-), J1.B7 (D-)
/USBD+: D1.6 (I/O1), U1.1 (UD+)
/USBD-: D1.4 (I/O2), U1.2 (UD-)
/VDDCR: C15.1, C16.1, U3.6 (VDDCR)
GND: C2.2, C3.2, C4.2, C5.2, C6.2, C7.2, C8.1, C9.2, C10.2, C11.2, C12.2, C13.2, C14.2, C15.2, C16.2, D1.2 (GND), D6.2 (GND), J1.A1 (GND), J1.A12 (GND), J1.B1 (GND), J1.B12 (GND), J1.S1 (SHIELD), Q2.2 (E), Q4.2 (E), Q5.2 (E), R2.2, R4.2, R5.2, R6.2, R14.1, R16.2, R18.2, R41.1, R42.1, R43.1, SW1.1, U1.3 (GND), U1.11 (GND), U2.1 (GND), U2.15 (GND), U2.38 (GND), U2.39 (GND), U3.24 (TXD2), U3.25 (TXD3), U3.33 (VSS); also elsewhere on the board
OUT1: R5.1, R7.2, U2.16 (IO13)
OUT2: R6.1, R8.2, U2.27 (IO16)
PHYPWR: Q2.1 (B), R14.2, U2.14 (IO12)
POE+: J4.9 (V+); also elsewhere on the board
POE-: J4.10 (V-); also elsewhere on the board

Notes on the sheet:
OPÇÕES DE CONECTORES RJ45 UDE CORP RB1-ZZ-0266 JLCPCB C409617 HCTL HC931147C-M897-A JLCPCB C3021372 HANRUN HY931147C JLCPCB C91754 ABRACON ARJP11A-MASA-B-A-FMU2 MOUSER 815-ARJP11AMAFMU2 CUI DEVICES CRJ005-M1-TH MOUSER 490-CRJ005-M1-TH SEM LEDS SEM DIODOS MDD MB6S JLCPCB C2487 PONTE RETIFICADORA
ESP32 TEMPLATE FOR GPIO ASSIGNMENT {"NAME":"ESP-POE-2RL-V1","GPIO":[0,3200,0,3232,0,0,0,0,5536,224,0,0,225,0,5600,0,0,0,0,5568,0,0,0,0,0,0,0,0,608,640,0,0,0,0,0,0],"FLAG":0,"BASE":1} https://tasmota.github.io/docs/Templates/
RESISTORS: 62,5mW WHERE NOT SPECIFIED
ESP32 PIN ASSIGNMENT PIN PORT FUNCTION COMPONENT 25 GPIO0 AUTO FLASH MODE 0 35 GPIO1 SERIAL TX 3200 24 GPIO2 - 0 34 GPIO3 SERIAL RX 3232 26 GPIO4 - 0 29 GPIO5 - 0 20 GPIO6 - 0 21 GPIO7 - 0 22 GPIO8 - 0 17 GPIO9 - 0 18 GPIO10 - 0 19 GPIO11 - 0 14 GPIO12 PHY POWER 5536 16 GPIO13 RELAY 1 224 13 GPIO14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
RTS DTR IO0 EN Low Low High High Low High High Low High Low Low High High High High High

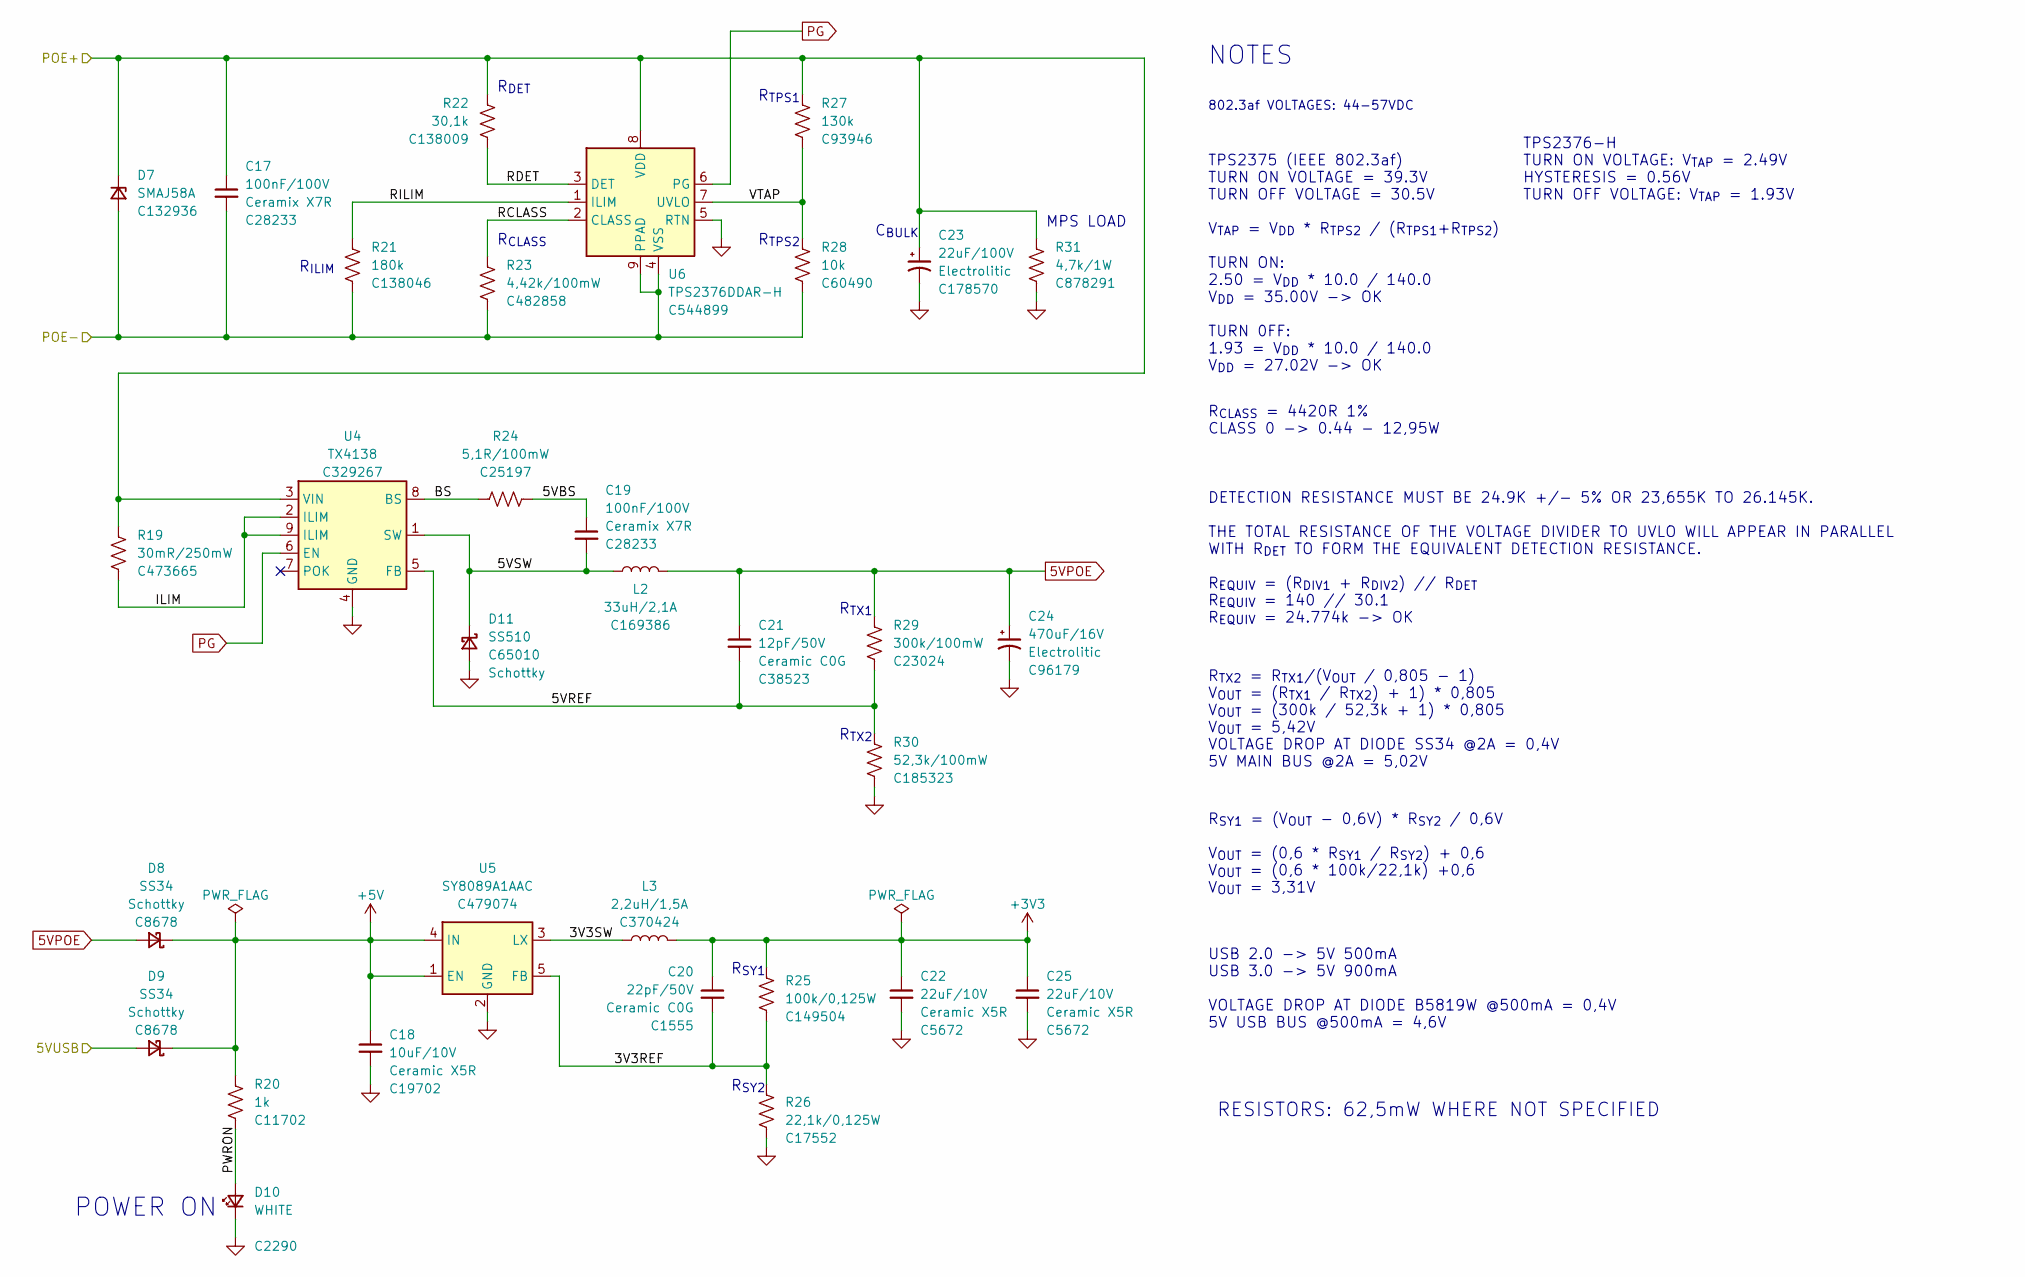
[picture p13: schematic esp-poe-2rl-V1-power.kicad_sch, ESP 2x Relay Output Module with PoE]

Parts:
C17: 100nF/100V; C_0805_2012Metric; Mfr PN CL21B104KCFNNNE; JLCPCB BOM 1
C18: 10uF/10V; C_0603_1608Metric; Mfr PN CL10A106KP8NNNC; JLCPCB BOM 1
C19: 100nF/100V; C_0805_2012Metric; Mfr PN CL21B104KCFNNNE; LCSC Part # C28233
C20: 22pF/50V; C_0402_1005Metric; Mfr PN 0402CG220J500NT; JLCPCB BOM 1
C21: 12pF/50V; C_0603_1608Metric; Mfr PN CL10C120JB8NNNC; JLCPCB BOM 1
C22, C25: 22uF/10V; C_1206_3216Metric; Mfr PN CL31A226KPHNNNE; JLCPCB BOM 1
C23: 22uF/100V; CP_Elec_8x10.5; Mfr PN EEEFK2A220P; LCSC Part # C178570
C24: 470uF/16V; CP_Elec_8x10.5; Mfr PN CS1C471M-CRF10; JLCPCB BOM 1
D7: SMAJ58A; D_SMA; Mfr PN SMAJ58A-TR; JLCPCB BOM 1
D8, D9: SS34; D_SMA; Mfr PN SS34; JLCPCB BOM 1
D10: WHITE; LED_0603_1608Metric; Mfr PN KT-0603W; LCSC Part # C2290
D11: SS510; D_SMA; Mfr PN SS510; JLCPCB BOM 1
L2: 33uH/2,1A; L_12x12mm_h6mm; Mfr PN SWRB1205S-330MT; JLCPCB BOM 1
L3: 2,2uH/1,5A; L_3x3mm_h1.5mm; Mfr PN SPH3015H2R2MT; JLCPCB BOM 1
R19: 30mR/250mW; R_1206_3216Metric; Mfr PN 1206W3F300MT5E; LCSC Part # C473665
R20: 1k; R_0402_1005Metric; Mfr PN 0402WGF1001TCE; LCSC Part # C11702
R21: 180k; R_0402_1005Metric; Mfr PN RC0402FR-07180KL; JLCPCB BOM 1
R22: 30,1k; R_0402_1005Metric; Mfr PN RC0402FR-0730K1L; JLCPCB BOM 1
R23: 4,42k/100mW; R_0603_1608Metric; Mfr PN RC0603FR-074K42L; JLCPCB BOM 1
R24: 5,1R/100mW; R_0603_1608Metric; Mfr PN 0603WAF510KT5E; LCSC Part # C25197
R25: 100k/0,125W; R_0805_2012Metric; Mfr PN 0805W8F1003T5E; JLCPCB BOM 1
R26: 22,1k/0,125W; R_0805_2012Metric; Mfr PN 0805W8F2212T5E; JLCPCB BOM 1
R27: 130k; R_0402_1005Metric; Mfr PN RC0402FR-07130KL; JLCPCB BOM 1
R28: 10k; R_0402_1005Metric; Mfr PN RC0402FR-0710KL; JLCPCB BOM 1
R29: 300k/100mW; R_0603_1608Metric; Mfr PN 0603WAF3003T5E; JLCPCB BOM 1
R30: 52,3k/100mW; R_0603_1608Metric; Mfr PN RC0603FR-0752K3L; JLCPCB BOM 1
R31: 4,7k/1W; R_2512_6332Metric; Mfr PN RC2512JK-074K7L; JLCPCB BOM 1
U4: TX4138; SOIC-8-1EP_3.9x4.9mm_P1.27mm_EP2.41x3.81mm_ThermalVias; Mfr PN TX4138; JLCPCB BOM 1
U5: SY8089A1AAC; SOT-23-5_Shorter_Pins; Mfr PN SY8089A1AAC; JLCPCB BOM 1
U6: TPS2376DDAR-H; SOIC-8-1EP_3.9x4.9mm_P1.27mm_EP2.95x4.9mm_Mask2.71x3.4mm_Th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; Mfr PN TPS2376DDAR-H; JLCPCB BOM 1

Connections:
5VPOE: C21.1, C24.1, D8.2 (A), L2.2, R29.1
5VUSB: D9.2 (A); also elsewhere on the board
+3V3: C20.1, C22.1, C25.1, L3.2, R25.1; also elsewhere on the board
+5V: C18.1, D8.1 (K), D9.1 (K), R20.1, U5.1 (EN), U5.4 (IN); also elsewhere on the board
/POWER/3V3REF: C20.2, R25.2, R26.1, U5.5 (FB)
/POWER/3V3SW: L3.1, U5.3 (LX)
/POWER/5VBS: C19.1, R24.1
/POWER/5VREF: C21.2, R29.2, R30.1, U4.5 (FB)
/POWER/5VSW: C19.2, D11.1 (K), L2.1, U4.1 (SW)
/POWER/BS: R24.2, U4.8 (BS)
/POWER/ILIM: R19.2, U4.2 (ILIM), U4.9 (ILIM)
/POWER/PWRON: D10.2 (A), R20.2
/POWER/RCLASS: R23.1, U6.2 (CLASS)
/POWER/RDET: R22.2, U6.3 (DET)
/POWER/RILIM: R21.1, U6.1 (ILIM)
/POWER/VTAP: R27.2, R28.1, U6.7 (UVLO)
GND: C18.2, C22.2, C23.2, C24.2, C25.2, D10.1 (K), D11.2 (A), R26.2, R30.2, R31.2, U4.4 (GND), U5.2 (GND), U6.5 (RTN); also elsewhere on the board
PG: U4.6 (EN), U6.6 (PG)
POE+: C17.1, C23.1, D7.1 (K), R19.1, R22.1, R27.1, R31.1, U4.3 (VIN), U6.8 (VDD); also elsewhere on the board
POE-: C17.2, D7.2 (A), R21.2, R23.2, R28.2, U6.4 (VSS), U6.9 (PPAD); also elsewhere on the board

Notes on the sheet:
R_{TPS1}
R_{TX2}
DETECTION RESISTANCE MUST BE 24.9K +/- 5% OR 23,655K TO 26.145K. THE TOTAL RESISTANCE OF THE VOLTAGE DIVIDER TO UVLO WILL APPEAR IN PARALLEL WITH R_{DET} TO FORM THE EQUIVALENT DETECTION RESISTANCE. R_{EQUIV} = (R_{DIV1} + R_{DIV2}) // R_{DET} R_{EQUIV} = 140 // 30.1 R_{EQUIV} = 24.774k -> OK
R_{SY2}
RESISTORS: 62,5mW WHERE NOT SPECIFIED
POWER ON
R_{CLASS} = 4420R 1% CLASS 0 -> 0.44 - 12,95W
R_{SY1}
R_{CLASS}
R_{TX2} = R_{TX1}/(V_{OUT} / 0,805 - 1) V_{OUT} = (R_{TX1} / R_{TX2}) + 1) * 0,805 V_{OUT} = (300k / 52,3k + 1) * 0,805 V_{OUT} = 5,42V VOLTAGE DROP AT DIODE SS34 @2A = 0,4V 5V MAIN BUS @2A = 5,02V
C_{BULK}
R_{ILIM}
USB 2.0 -> 5V 500mA USB 3.0 -> 5V 900mA VOLTAGE DROP AT DIODE B5819W @500mA = 0,4V 5V USB BUS @500mA = 4,6V
TPS2375 (IEEE 802.3af) TURN ON VOLTAGE = 39.3V TURN OFF VOLTAGE = 30.5V
TPS2376-H TURN ON VOLTAGE: V_{TAP} = 2.49V HYSTERESIS = 0.56V TURN OFF VOLTAGE: V_{TAP} = 1.93V
R_{SY1} = (V_{OUT} - 0,6V) * R_{SY2} / 0,6V V_{OUT} = (0,6 * R_{SY1} / R_{SY2}) + 0,6 V_{OUT} = (0,6 * 100k/22,1k) +0,6 V_{OUT} = 3,31V
R_{TPS2}
R_{TX1}
NOTES
MPS LOAD
R_{DET}
802.3af VOLTAGES: 44-57VDC
V_{TAP} = V_{DD} * R_{TPS2} / (R_{TPS1}+R_{TPS2}) TURN ON: 2.50 = V_{DD} * 10.0 / 140.0 V_{DD} = 35.00V -> OK TURN 0FF: 1.93 = V_{DD} * 10.0 / 140.0 V_{DD} = 27.02V -> OK

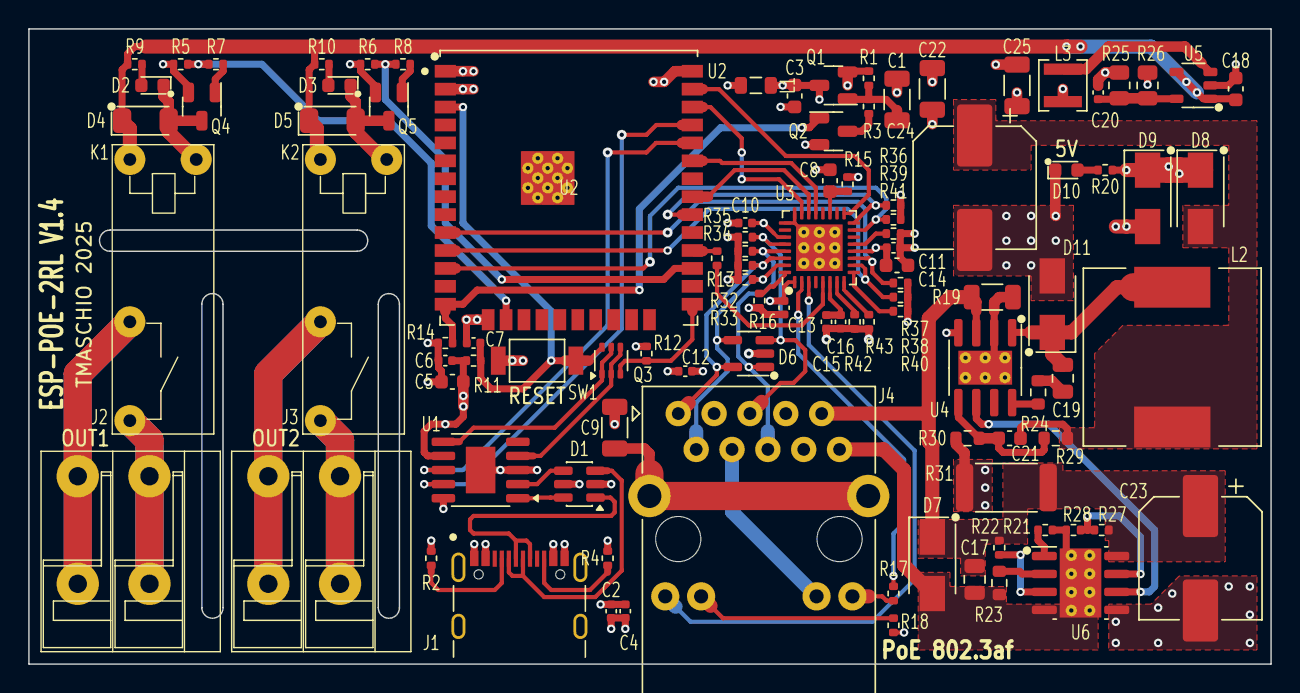
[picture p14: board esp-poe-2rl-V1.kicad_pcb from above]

Board: 4 copper layers, 88.0 x 45.0 mm, 100 parts (0 on the bottom side), 75 nets.

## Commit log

2023-08-02 First iteration
    [esp-poe-2rl-V1-expanders.kicad_sch, esp-poe-2rl-V1-inputs-1.kicad_sch, esp-poe-2rl-V1-lan.kicad_sch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]
2023-08-07 Searching for the right connector...
    [esp-poe-2rl-V1-power.kicad_sch, esp-poe-2rl-V1.kicad_sch]
2023-08-08 Working on PoE frontend.
    [esp-poe-2rl-V1-lan.kicad_sch, esp-poe-2rl-V1-mcu.kicad_sch, esp-poe-2rl-V1-outputs-1.kicad_sch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]
2023-08-09 Development continues!
    [esp-poe-2rl-V1-mcu.kicad_sch, esp-poe-2rl-V1-power.kicad_sch, esp-poe-2rl-V1.kicad_sch]
2023-08-09 The dev saga goes on.
    [esp-poe-2rl-V1.kicad_sch]
2023-08-10 Dev fest.
    [esp-poe-2rl-V1.kicad_sch]
2023-08-11 Dev going on
    [esp-poe-2rl-V1.kicad_sch]
2023-08-11 Dev dev dev
    [esp-poe-2rl-V1.kicad_sch]
2023-08-12 dev goes on
    [esp-poe-2rl-V1.kicad_sch]
2023-08-14 Topology ok, checking components values
    [esp-poe-2rl-V1-lan.kicad_sch, esp-poe-2rl-V1-mcu.kicad_sch, esp-poe-2rl-V1-power.kicad_sch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]
2023-08-14 Revising components specs
    [esp-poe-2rl-V1-power.kicad_sch, esp-poe-2rl-V1.kicad_pcb, esp-poe-2rl-V1.kicad_sch]
2023-08-15 Reviewing components
    [esp-poe-2rl-V1-power.kicad_sch, esp-poe-2rl-V1.kicad_pcb, esp-poe-2rl-V1.kicad_sch]
2023-08-16 Starting layout
    [esp-poe-2rl-V1.kicad_pcb, esp-poe-2rl-V1.kicad_sch]
2023-08-16 Layout development
    [esp-poe-2rl-V1-power.kicad_sch, esp-poe-2rl-V1.kicad_pcb, esp-poe-2rl-V1.kicad_sch]
2023-08-17 Big layout
    [esp-poe-2rl-V1.kicad_pcb]
2023-08-17 PCB design
    [esp-poe-2rl-V1.kicad_pcb, esp-poe-2rl-V1.kicad_sch]
2023-08-18 Something, cant remember
    [esp-poe-2rl-V1.kicad_pcb]
2023-08-18 Squeezing layout
    [esp-poe-2rl-V1.kicad_pcb]
2023-08-18 Layout optimization
    [esp-poe-2rl-V1.kicad_pcb]
2023-08-18 Replace power connectors
    [esp-poe-2rl-V1.kicad_sch]
2023-08-19 Connectors rotated 180deg
    [esp-poe-2rl-V1.kicad_pcb]
2023-08-24 Replaced relays
    [esp-poe-2rl-V1.kicad_pcb, esp-poe-2rl-V1.kicad_sch]
2023-08-25 PCB shrinking process in course
    [esp-poe-2rl-V1.kicad_pcb]
2023-08-26 PCB shrinking process
    [esp-poe-2rl-V1-power.kicad_sch, esp-poe-2rl-V1.kicad_pcb, esp-poe-2rl-V1.kicad_sch]
2023-08-27 Migrating layout to 4 layers
    [esp-poe-2rl-V1-power.kicad_sch, esp-poe-2rl-V1.kicad_pcb, esp-poe-2rl-V1.kicad_sch]
2023-08-27 PCB dev
    [esp-poe-2rl-V1.kicad_pcb, esp-poe-2rl-V1.kicad_sch]
2023-08-28 Last touches
    [esp-poe-2rl-V1-backup.kicad_pcb, esp-poe-2rl-V1-power.kicad_sch, esp-poe-2rl-V1.kicad_sch]
2023-08-29 Production testing
    [esp-poe-2rl-V1.kicad_pcb, esp-poe-2rl-V1.kicad_sch]
2023-09-02 Design optimization
    [esp-poe-2rl-V1.kicad_pcb]
2023-09-04 Tweaks to components
    [esp-poe-2rl-V1-backup.kicad_pcb, esp-poe-2rl-V1-power.kicad_sch, esp-poe-2rl-V1.kicad_pcb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]
2023-09-04 New board image
    [esp-poe-2rl-V1.kicad_pcb]
2023-09-05 Update image
    [esp-poe-2rl-V1-power.kicad_sch, esp-poe-2rl-V1.kicad_pcb, esp-poe-2rl-V1.kicad_sch]
2024-11-06 Update to Kicad V8
    [esp-poe-2rl-V1-power.kicad_sch, esp-poe-2rl-V1.kicad_pcb, esp-poe-2rl-V1.kicad_sch]
2024-11-25 Added temperature sensor
    [esp-poe-2rl-V1-power.kicad_sch, esp-poe-2rl-V1.kicad_pcb, esp-poe-2rl-V1.kicad_sch]
2024-11-27 Added temperature sensor.
    [esp-poe-2rl-V1.kicad_pcb, esp-poe-2rl-V1.kicad_sch]
2024-11-27 Reviewing board for fabrication
    [esp-poe-2rl-V1-power.kicad_sch, esp-poe-2rl-V1.kicad_pcb, esp-poe-2rl-V1.kicad_sch]
2024-11-29 Preparations for fabrication
    [bom.csv, designators.csv, esp-poe-2rl-V1.kicad_pcb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]
2024-11-30 Selecting components at JLCPCB
    [bom.csv, esp-poe-2rl-V1-power.kicad_sch, esp-poe-2rl-V1.kicad_pcb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]
2024-12-02 Adjustment for case
    [bom.csv, esp-poe-2rl-V1.FCStd, esp-poe-2rl-V1.kicad_pcb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]
2024-12-02 Replaced RJ45 connector
    [bom.csv, esp-poe-2rl-V1-power.kicad_sch, esp-poe-2rl-V1.kicad_pcb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]
2024-12-03 Adjusting for component shortages at JLCPCB
    [bom.csv, esp-poe-2rl-V1.kicad_pcb, esp-poe-2rl-V1.kicad_sch]
2024-12-03 Adjust for components shortage at JLCPCB
    [esp-poe-2rl-V1.kicad_pcb]
2024-12-04 DIN holder
    [Encaixe Trilho DIN.FCStd, din-clip-adjustable - cópia.FCStd, din-clip-adjustable.FCStd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]
2024-12-05 Connectors repositioned to better fit the case
    [esp-poe-2rl-V1.kicad_pcb, positions.csv]
2025-04-14 Prefab checks
    [esp-poe-2rl-V1.kicad_pcb, positions.csv]
2025-06-24 Redoing routing because was too crapy
    [esp-poe-2rl-V1.kicad_pcb]
2025-06-24 Redoing routing
    [esp-poe-2rl-V1.kicad_pcb, esp-poe-2rl-V1.kicad_sch]
2025-06-29 Routing redone
    [esp-poe-2rl-V1.kicad_pcb]
2025-06-29 Production output
    [positions.csv]
2025-06-29 Files for release 1.3.0
    [esp-poe-2rl-V1-power.kicad_sch, esp-poe-2rl-V1.kicad_pcb, esp-poe-2rl-V1.kicad_sch]
2025-07-09 Generated fabrication files
    [esp-poe-2rl-V1.kicad_pcb]
2025-07-09 Fabrication file generated
    [bom.csv, esp-poe-2rl-V1.kicad_pcb, esp-poe-2rl-V1.kicad_sch]
2025-07-14 Fabrication updates
    [bom.csv, esp-poe-2rl-V1-power.kicad_sch, esp-poe-2rl-V1.kicad_pcb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]
2025-07-31 Update GPIO template info
    [esp-poe-2rl-V1.kicad_sch]
2025-07-31 Corrected leds connections on RJ45 jack
    [esp-poe-2rl-V1.kicad_pcb]
2026-07-04 Added CPU health LED
    [eumesmo-poe-2rl-v1.kicad_pcb]
2026-07-10 Adjusted the footprint for the reset switch.
    [eumesmo-poe-2rl-v1.kicad_pcb]
